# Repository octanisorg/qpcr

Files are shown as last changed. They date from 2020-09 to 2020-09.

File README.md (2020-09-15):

# Octanis qPCR

Quantitative PCR or sometimes called real-time PCR is a method to amplify a target DNA molecule and monitor its replication via fluorescence. The objective of this Octanis qPCR is to build a reliable and open qPCR machine for research purposes.

## COVID-19 and PCR

COVID-19 testing involves qPCR machines where an additional step needs to be completed prior to amplification. Using an enzyme called [Reverse Transcriptase](https://en.wikipedia.org/wiki/Reverse_transcriptase) the viral RNA is turned into DNA that the [Polymerase](https://en.wikipedia.org/wiki/Polymerase) can work with. 

## Current state

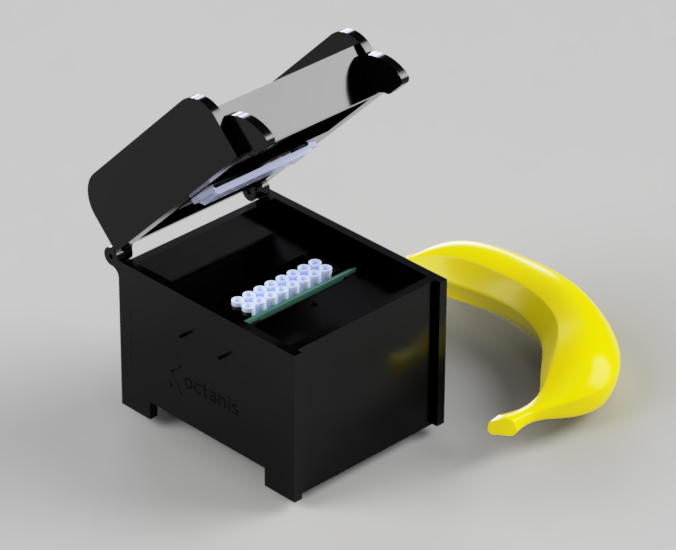
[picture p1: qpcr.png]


We are currently working on assembling the first PCBs and writing firmware. As we finalize the first prototype we will be updating this repository with our work in progress. 

If you are interested in contributing to the project [DM us](https://twitter.com/octanisorg). there are lots of cool sub-projects:
- STM32 firmware development
- SPICE simulation
- Case design
- Device GUI development

On our task list:
- Publication of an eBOM and mBOM.
- Collaboration with somebody making PCR tests/master mixes.
- Complete assembly as a STEP file. 

Completed:
- [Lid Heater PCB](https://pcb.im/share/dadb9a33574c403e)
- [16 Channel Excitation PCB](https://pcb.im/share/144b98556b9944f6)
- [8 Channel Emmision Sensing PCB](https://pcb.im/share/420ee10b3fee4fb8)
- [mainboard PCB](http://pcb.im/share/4b724f7b39da497d)

## Acknowledgements
- Chaibio, for the block and lid heater design, which we slightly modified.

## Sponsors
- [Octanis Instruments GmbH](https://www.octanis.ch) is helping with engineering and manufacturing.

## Similar projects
- [Chai Open qPCR](https://www.chaibio.com/openqpcr)
- [Ninja PCR](https://hackaday.io/project/174501-covid-19-detectors-300-real-time-pcr-50-lamp)

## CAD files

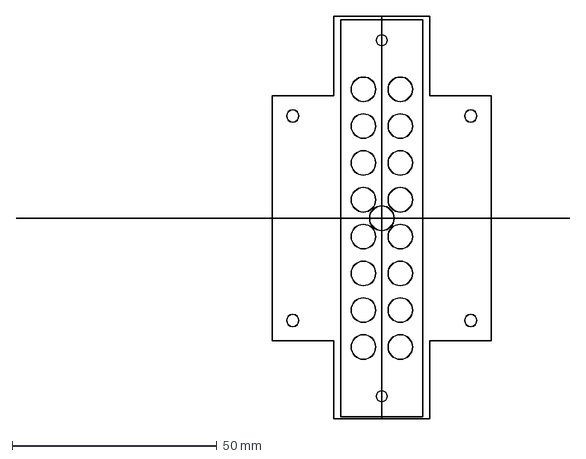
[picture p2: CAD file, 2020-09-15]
electronics/excitation-pcb/rev0/cutout.dxf
135.4 x 98.5 mm

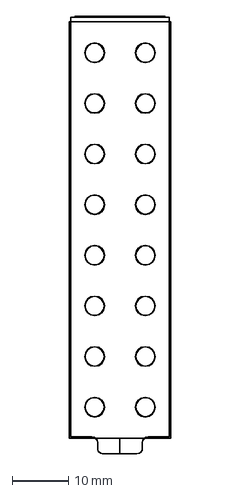
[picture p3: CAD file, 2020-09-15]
electronics/lidheater-pcb/rev0/cutout.dxf
18.0 x 77.8 mm

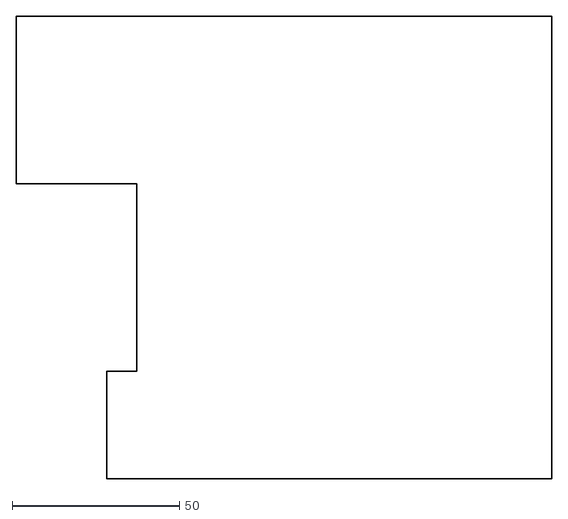
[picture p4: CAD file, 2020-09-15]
electronics/mainboard-pcb/rev0/qpcr_pcb_edge_cuts.dxf
160.0 x 138.0

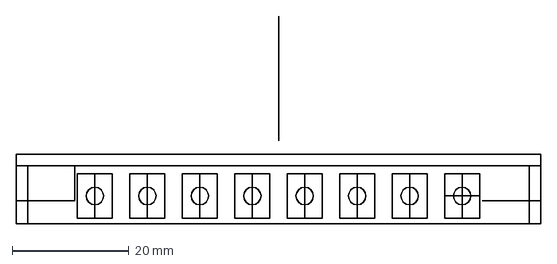
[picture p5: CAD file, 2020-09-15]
electronics/photodiode-pcb/rev0/cutout.dxf
90.0 x 35.7 mm

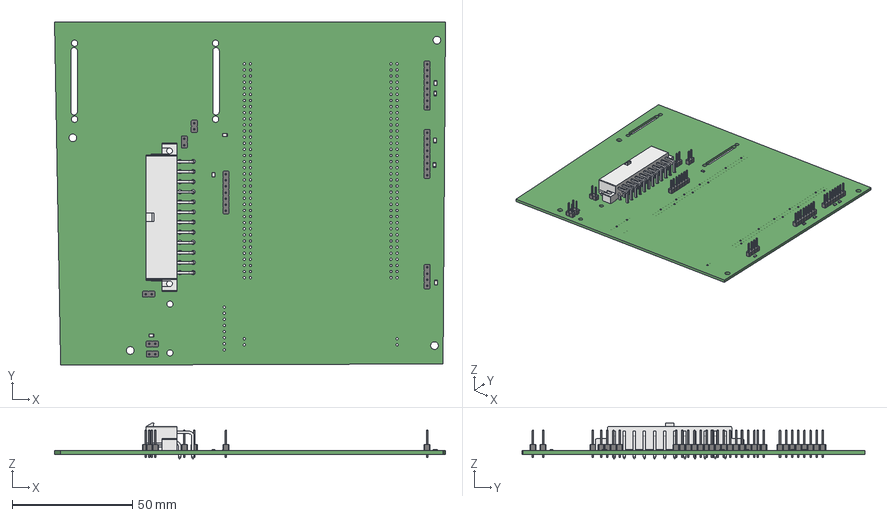
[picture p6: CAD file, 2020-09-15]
electronics/mainboard-pcb/3D_models/pcb_model.fcstd
162.6 x 142.7 x 14.9 mm

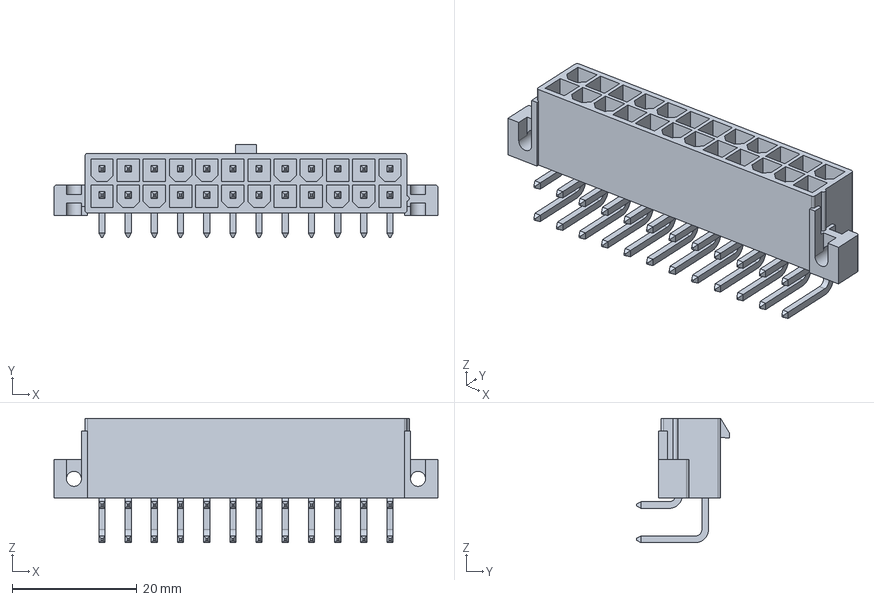
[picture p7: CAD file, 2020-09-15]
electronics/mainboard-pcb/3D_models/39291248.stp
61.6 x 14.9 x 19.9 mm

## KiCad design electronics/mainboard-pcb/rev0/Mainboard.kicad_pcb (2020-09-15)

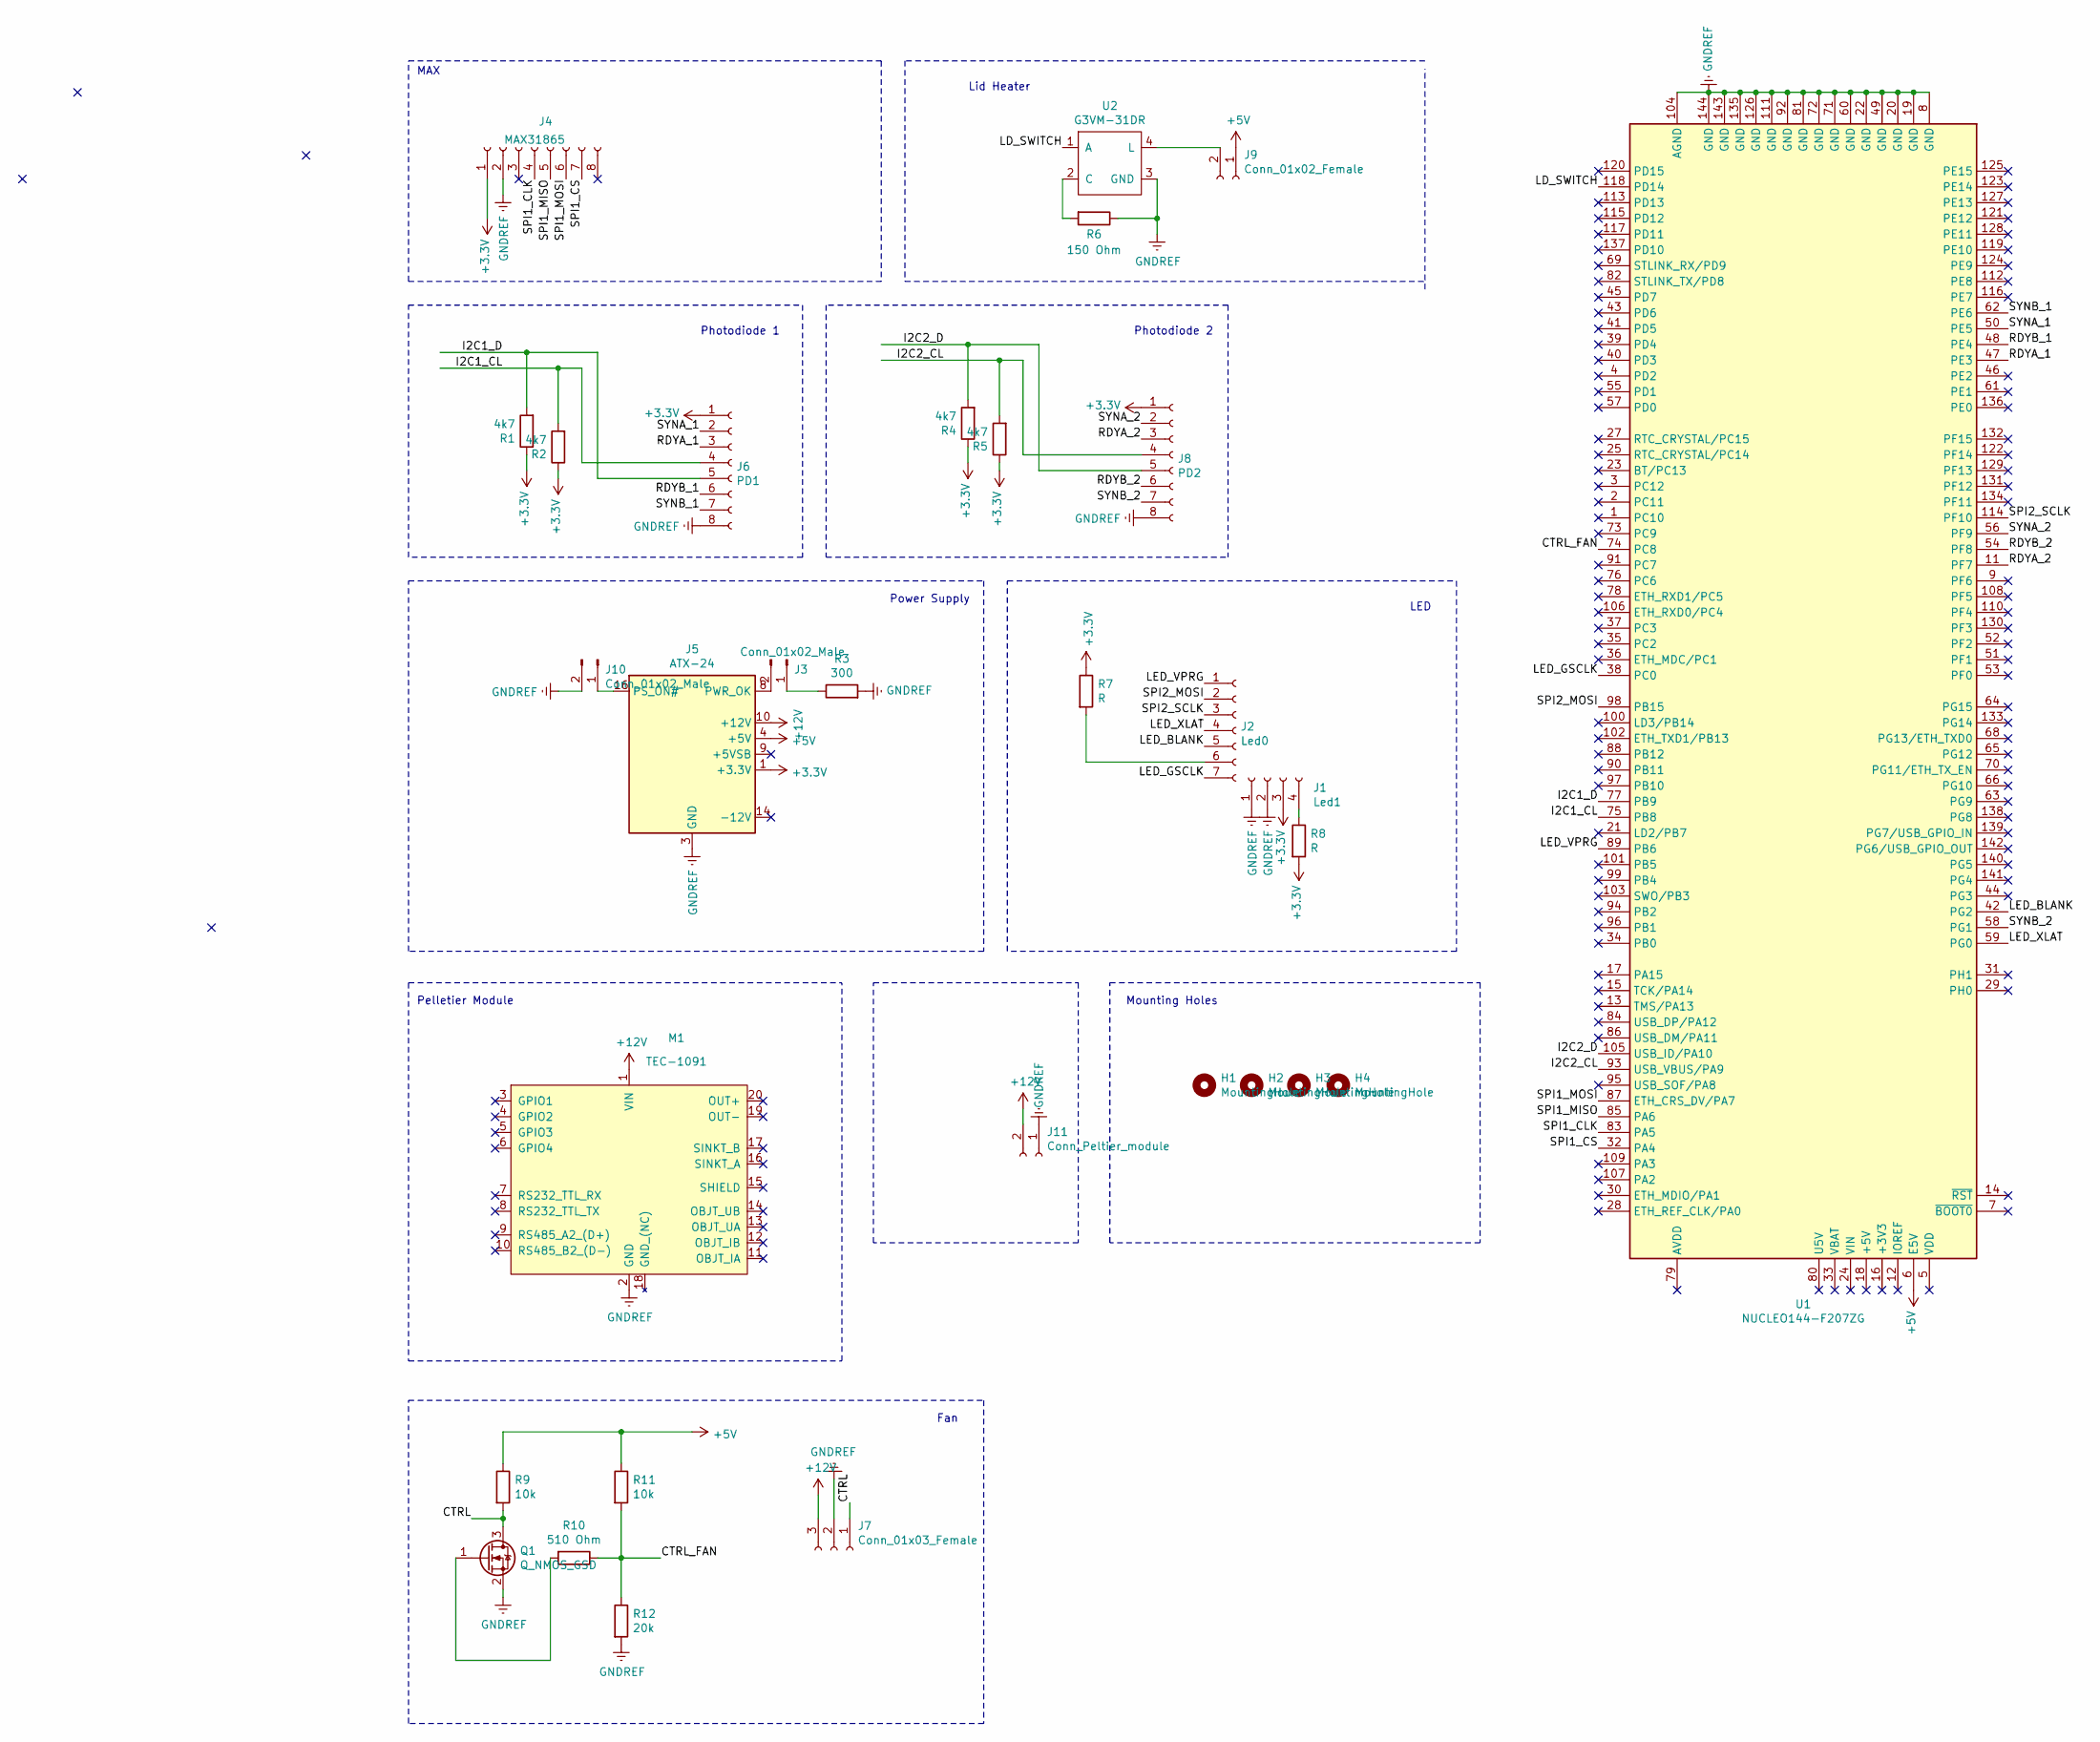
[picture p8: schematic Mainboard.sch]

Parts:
H1, H2, H3, H4: MountingHole; MountingHole_3.2mm_M3
J1: Led1; PinHeader_1x04_P2.54mm_Vertical
J2: Led0; PinHeader_1x07_P2.54mm_Vertical
J3, J10: Conn_01x02_Male; PinHeader_1x02_P2.54mm_Vertical
J4: MAX31865
J5: ATX-24; Molex_Mini-Fit_Jr_5569-24A1_2x12_P4.20mm_Horizontal; MPN 39291248
J6: PD1; PinHeader_1x08_P2.54mm_Vertical
J7: Conn_01x03_Female; PinHeader_1x03_P2.54mm_Vertical
J8: PD2; PinHeader_1x08_P2.54mm_Vertical
J9: Conn_01x02_Female; PinHeader_1x02_P2.54mm_Vertical
J11: Conn_Peltier_module; PinHeader_1x02_P2.54mm_Vertical
M1: TEC-1091; TEC-1091_alternate_pads; MPN TEC-1091
Q1: Q_NMOS_GSD; SOT-323_SC-70_Handsoldering; MPN SSM3K345R,LF
R1, R2, R4, R5: 4k7; R_0805_2012Metric_Pad1.15x1.40mm_HandSolder
R3: 300; R_0805_2012Metric_Pad1.15x1.40mm_HandSolde
R6: 150 Ohm; R_0805_2012Metric_Pad1.15x1.40mm_HandSolde
R7, R8: R; R_0805_2012Metric_Pad1.15x1.40mm_HandSolder
R9, R11: 10k; R_0805_2012Metric_Pad1.15x1.40mm_HandSolder
R10: 510 Ohm; R_0805_2012Metric_Pad1.15x1.40mm_HandSolder
R12: 20k; R_0805_2012Metric_Pad1.15x1.40mm_HandSolder
U1: NUCLEO144-F207ZG; ST_Morpho_Connector_144_STLink; MPN2 NUCLEO-F303ZE
U2: G3VM-31DR; MPN G3VM-31DR

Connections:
+3V3: J1.3, J4.1, J5.1 (+3.3V), J5.2 (+3.3V), J5.12 (+3.3V), J5.13 (+3.3V), J6.1, J8.1, R1.1, R2.1, R4.1, R5.1, R7.1, R8.2
+5V: J5.4 (+5V), J5.6 (+5V), J5.21 (+5V), J5.22 (+5V), J5.23 (+5V), J9.1, R9.1, R11.1, U1.6 (E5V)
+12V: J5.10 (+12V), J5.11 (+12V), J7.3, J11.2, M1.1 (VIN)
/CTRL: J7.1, Q1.3 (D), R9.2
/CTRL_FAN: R10.1, R11.2, R12.1, U1.74 (PC8)
/I2C1_CL: J6.4, R2.2, U1.75 (PB8)
/I2C1_D: J6.5, R1.2, U1.77 (PB9)
/I2C2_CL: J8.4, R5.2, U1.93 (USB_VBUS/PA9)
/I2C2_D: J8.5, R4.2, U1.105 (USB_ID/PA10)
/LD_SWITCH: U1.118 (PD14), U2.1 (A)
/LED_BLANK: J2.5, U1.42 (PG2)
/LED_GSCLK: J2.7, U1.38 (PC0)
/LED_VPRG: J2.1, U1.89 (PB6)
/LED_XLAT: J2.4, U1.59 (PG0)
/RDYA_1: J6.3, U1.47 (PE3)
/RDYA_2: J8.3, U1.11 (PF7)
/RDYB_1: J6.6, U1.48 (PE4)
/RDYB_2: J8.6, U1.54 (PF8)
/SPI1_CLK: J4.4, U1.83 (PA5)
/SPI1_CS: J4.7, U1.32 (PA4)
/SPI1_MISO: J4.5, U1.85 (PA6)
/SPI1_MOSI: J4.6, U1.87 (ETH_CRS_DV/PA7)
/SPI2_MOSI: J2.2, U1.98 (PB15)
/SPI2_SCLK: J2.3, U1.114 (PF10)
/SYNA_1: J6.2, U1.50 (PE5)
/SYNA_2: J8.2, U1.56 (PF9)
/SYNB_1: J6.7, U1.62 (PE6)
/SYNB_2: J8.7, U1.58 (PG1)
GNDREF: J1.1, J1.2, J4.2, J5.3 (GND), J5.5 (GND), J5.7 (GND), J5.15 (GND), J5.17 (GND), J5.18 (GND), J5.19 (GND), J5.24 (GND), J6.8, J7.2, J8.8, J10.2, J11.1, M1.2 (GND), Q1.2 (S), R3.2, R6.1, R12.2, U1.8 (GND), U1.19 (GND), U1.20 (GND), U1.22 (GND), U1.49 (GND), U1.60 (GND), U1.71 (GND), U1.72 (GND), U1.81 (GND), U1.92 (GND), U1.104 (AGND), U1.111 (GND), U1.126 (GND), U1.135 (GND), U1.143 (GND), U1.144 (GND), U2.3 (GND)
unnamed: J1.4, R8.1
unnamed: J2.6, R7.2
unnamed: J3.1, R3.1
unnamed: J3.2, J5.8 (PWR_OK)
unnamed: J9.2, U2.4 (L)
unnamed: J5.16 (PS_ON#), J10.1
unnamed: Q1.1 (G), R10.2
unnamed: R6.2, U2.2 (C)

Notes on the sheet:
Lid Heater
Power Supply
MAX
Photodiode 1
Photodiode 2
LED
Pelletier Module
Fan
Mounting Holes

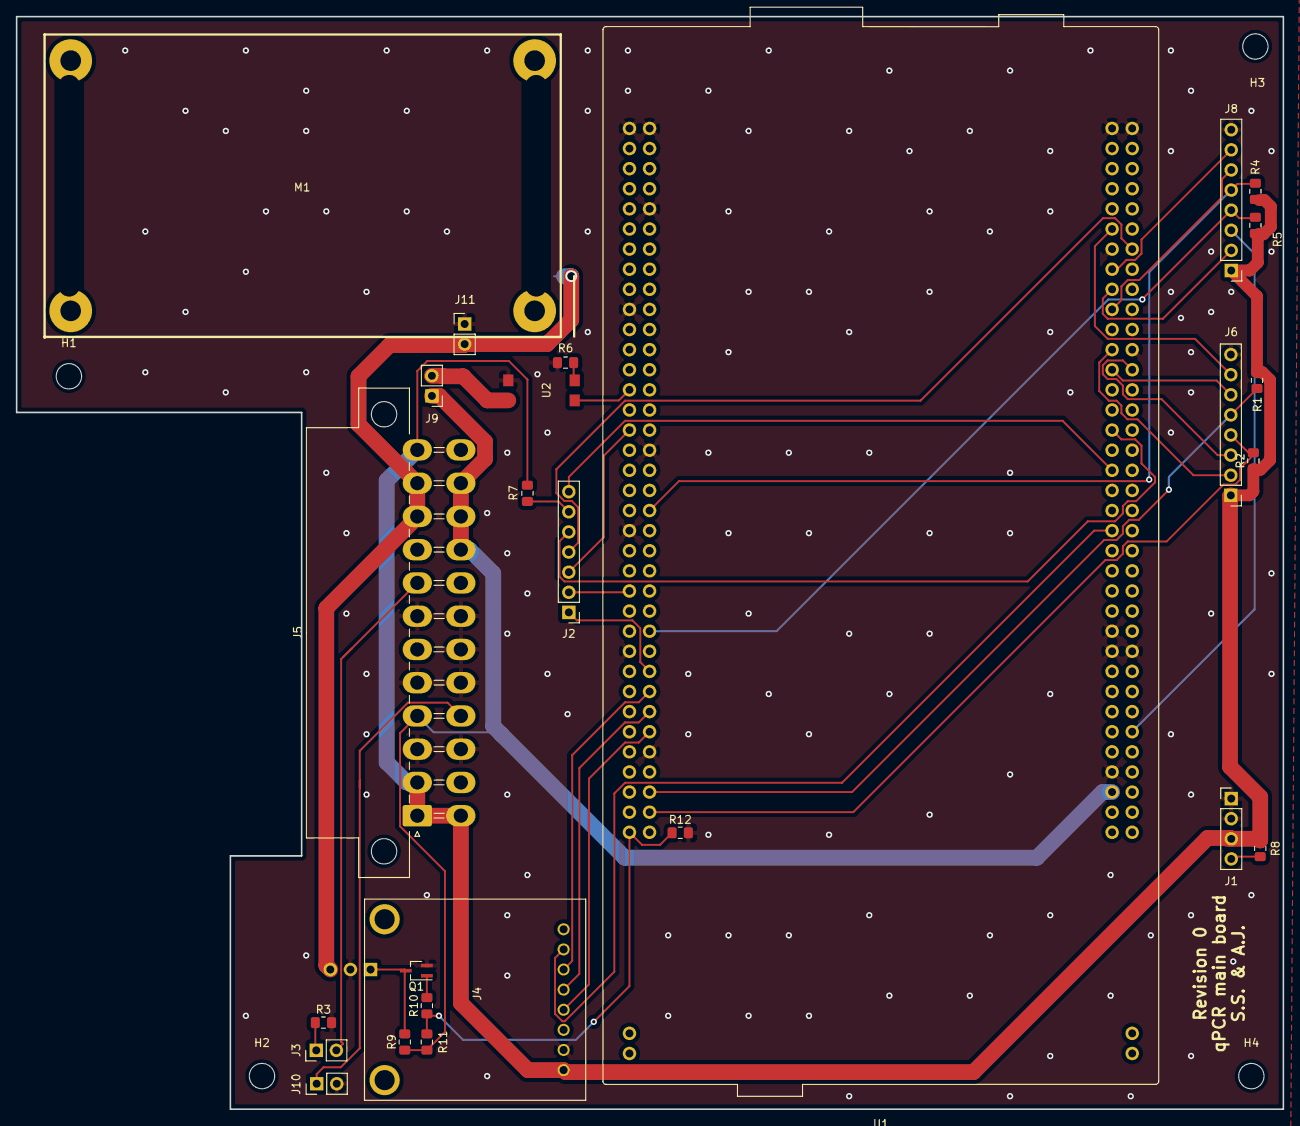
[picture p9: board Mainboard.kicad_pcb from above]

Board: 2 copper layers, 160.0 x 138.0 mm, 31 parts (1 on the bottom side), 37 nets.

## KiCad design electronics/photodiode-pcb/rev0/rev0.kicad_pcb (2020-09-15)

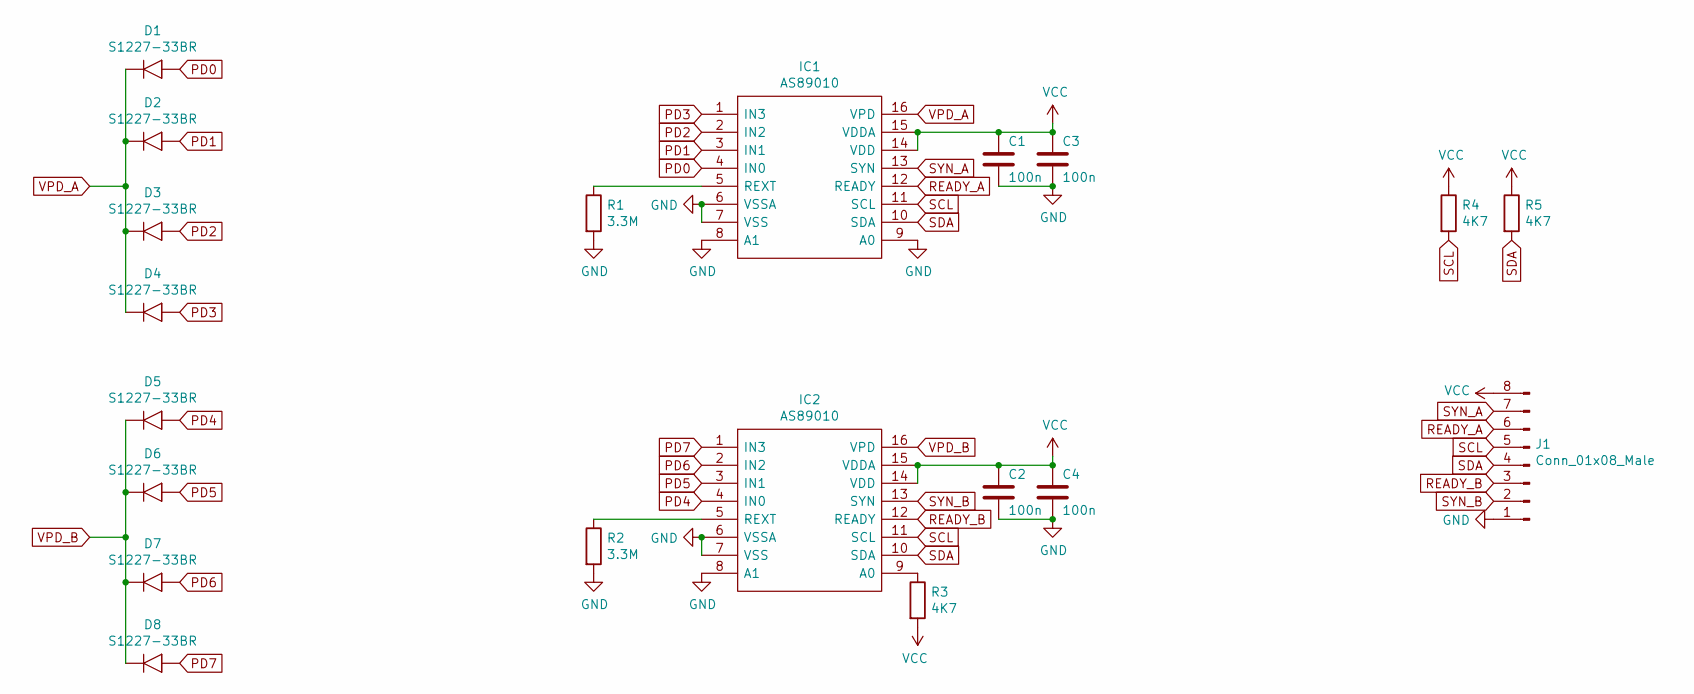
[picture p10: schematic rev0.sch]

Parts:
C1, C2, C3, C4: 100n; C_0402_1005Metric
D1, D2, D3, D4, D5, D6, D7, D8: S1227-33BR; MPN S1227-33BR
IC1, IC2: AS89010; SOP64P600X175-16N; Manufacturer_Part_Number AS89010; Mouser Part Number 985-AS89010
J1: Conn_01x08_Male; PinHeader_1x08_P1.00mm_Vertical
R1, R2: 3.3M; R_1206_3216Metric
R3, R4, R5: 4K7; R_0402_1005Metric

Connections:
GND: C1.2, C2.2, C3.2, C4.2, IC1.6 (VSSA), IC1.7 (VSS), IC1.8 (A1), IC1.9 (A0), IC2.6 (VSSA), IC2.7 (VSS), IC2.8 (A1), J1.1, R1.2, R2.2
unnamed: IC1.5 (REXT), R1.1
unnamed: IC2.5 (REXT), R2.1
unnamed: IC2.9 (A0), R3.1
PD0: D1.1, IC1.4 (IN0)
PD1: D2.1, IC1.3 (IN1)
PD2: D3.1, IC1.2 (IN2)
PD3: D4.1, IC1.1 (IN3)
PD4: D5.1, IC2.4 (IN0)
PD5: D6.1, IC2.3 (IN1)
PD6: D7.1, IC2.2 (IN2)
PD7: D8.1, IC2.1 (IN3)
READY_A: IC1.12 (READY), J1.6
READY_B: IC2.12 (READY), J1.3
SCL: IC1.11 (SCL), IC2.11 (SCL), J1.5, R4.2
SDA: IC1.10 (SDA), IC2.10 (SDA), J1.4, R5.2
SYN_A: IC1.13 (SYN), J1.7
SYN_B: IC2.13 (SYN), J1.2
VCC: C1.1, C2.1, C3.1, C4.1, IC1.14 (VDD), IC1.15 (VDDA), IC2.14 (VDD), IC2.15 (VDDA), J1.8, R3.2, R4.1, R5.1
VPD_A: D1.2, D2.2, D3.2, D4.2, IC1.16 (VPD)
VPD_B: D5.2, D6.2, D7.2, D8.2, IC2.16 (VPD)

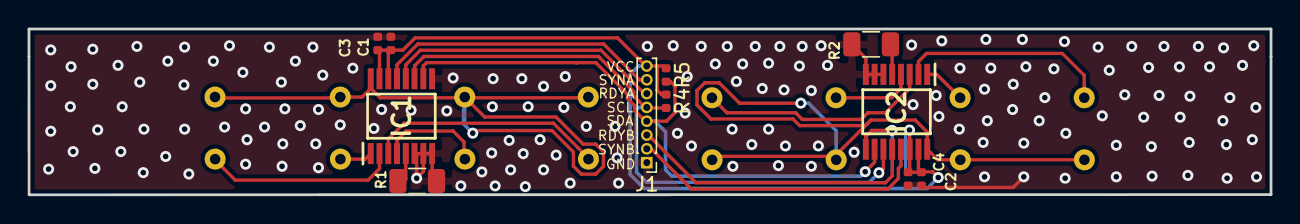
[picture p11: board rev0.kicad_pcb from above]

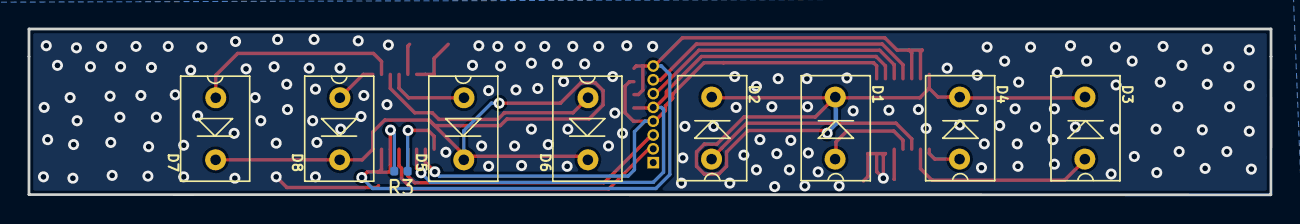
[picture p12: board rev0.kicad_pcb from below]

Board: 2 copper layers, 90.0 x 12.0 mm, 20 parts (9 on the bottom side), 21 nets.

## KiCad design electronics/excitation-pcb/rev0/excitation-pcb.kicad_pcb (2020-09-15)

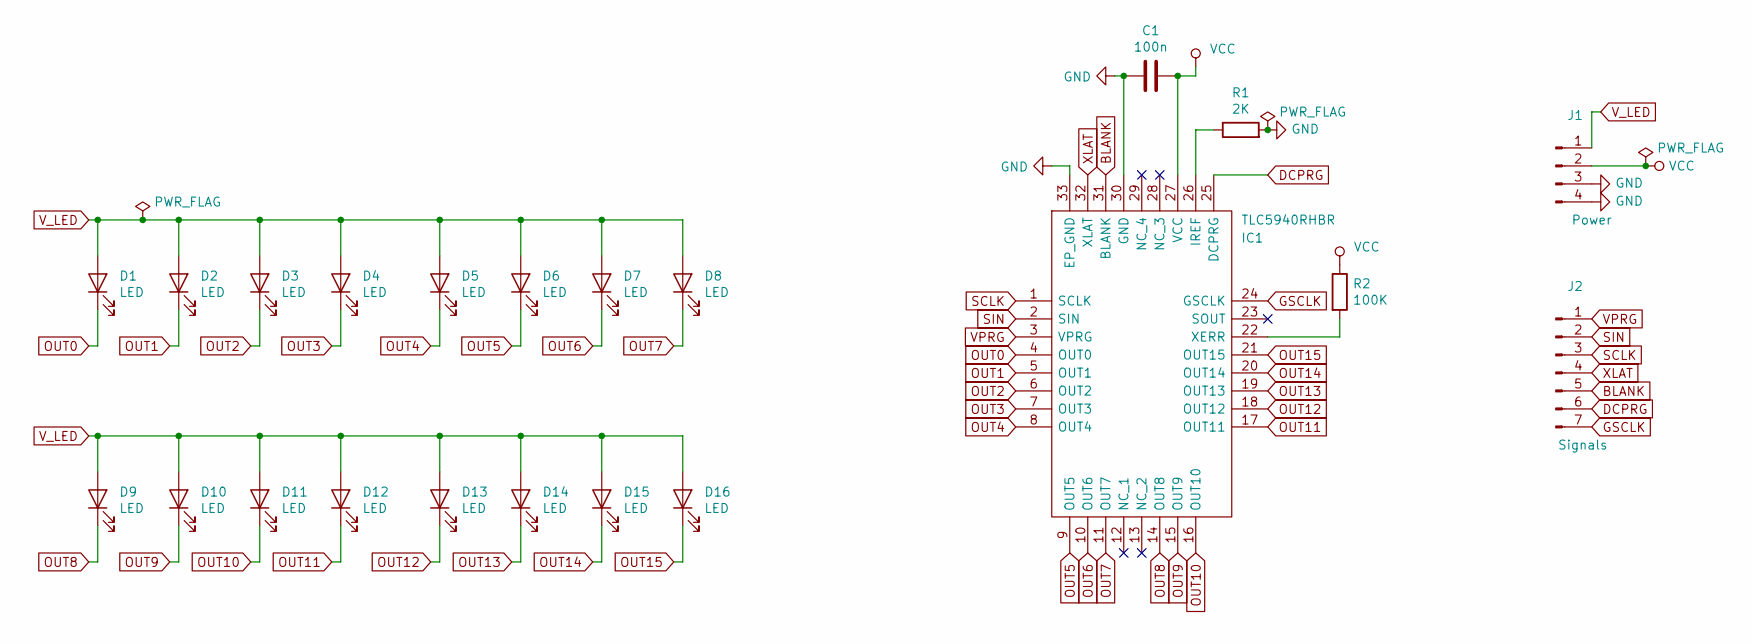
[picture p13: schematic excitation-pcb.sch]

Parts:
C1: 100n; C_0603_1608Metric
D1: LED; LED_D5.0mm; MPN C503B-BAS-CY0C0461
D2, D3, D4, D5, D6, D7, D8, D9, D10, D11, D12, D13, D14, D15, D16: LED; LED_D5.0mm
IC1: TLC5940RHBR; QFN50P500X500X100-33N-D; Manufacturer_Part_Number TLC5940RHBR; Mouser Part Number 595-TLC5940RHBR
J1: Power; PinHeader_1x04_P2.54mm_Vertical
J2: Signals; PinHeader_1x07_P2.54mm_Vertical
R1: 2K; R_0603_1608Metric
R2: 100K; R_0603_1608Metric

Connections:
BLANK: IC1.31 (BLANK), J2.5
DCPRG: IC1.25 (DCPRG), J2.6
GND: C1.2, IC1.30 (GND), IC1.33 (EP_GND), J1.3, J1.4, R1.2
GSCLK: IC1.24 (GSCLK), J2.7
unnamed: IC1.22 (XERR), R2.2
unnamed: IC1.26 (IREF), R1.1
OUT0: D1.1 (K), IC1.4 (OUT0)
OUT1: D2.1 (K), IC1.5 (OUT1)
OUT2: D3.1 (K), IC1.6 (OUT2)
OUT3: D4.1 (K), IC1.7 (OUT3)
OUT4: D5.1 (K), IC1.8 (OUT4)
OUT5: D6.1 (K), IC1.9 (OUT5)
OUT6: D7.1 (K), IC1.10 (OUT6)
OUT7: D8.1 (K), IC1.11 (OUT7)
OUT8: D9.1 (K), IC1.14 (OUT8)
OUT9: D10.1 (K), IC1.15 (OUT9)
OUT10: D11.1 (K), IC1.16 (OUT10)
OUT11: D12.1 (K), IC1.17 (OUT11)
OUT12: D13.1 (K), IC1.18 (OUT12)
OUT13: D14.1 (K), IC1.19 (OUT13)
OUT14: D15.1 (K), IC1.20 (OUT14)
OUT15: D16.1 (K), IC1.21 (OUT15)
SCLK: IC1.1 (SCLK), J2.3
SIN: IC1.2 (SIN), J2.2
VCC: C1.1, IC1.27 (VCC), J1.2, R2.1
VPRG: IC1.3 (VPRG), J2.1
V_LED: D1.2 (A), D2.2 (A), D3.2 (A), D4.2 (A), D5.2 (A), D6.2 (A), D7.2 (A), D8.2 (A), D9.2 (A), D10.2 (A), D11.2 (A), D12.2 (A), D13.2 (A), D14.2 (A), D15.2 (A), D16.2 (A), J1.1
XLAT: IC1.32 (XLAT), J2.4

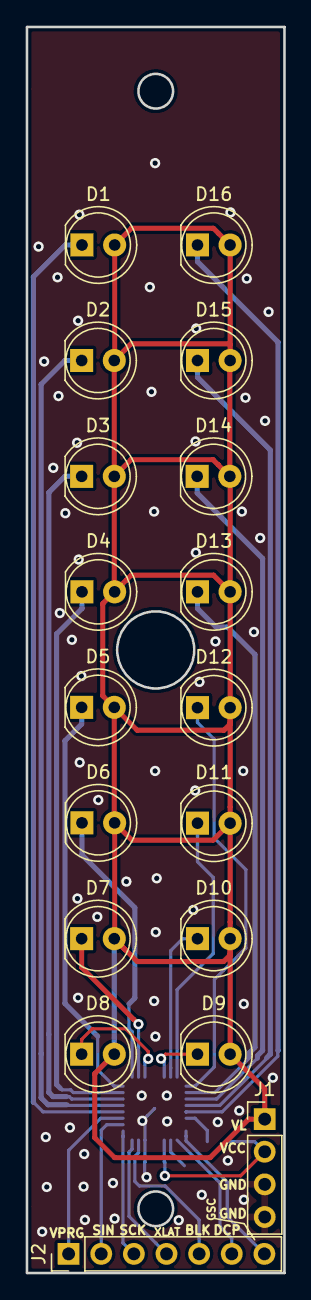
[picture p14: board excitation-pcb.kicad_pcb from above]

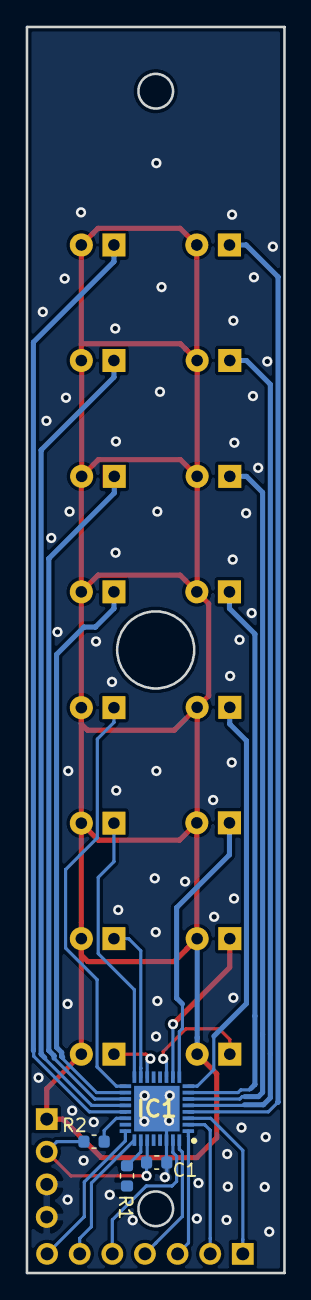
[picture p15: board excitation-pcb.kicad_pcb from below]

Board: 2 copper layers, 20.0 x 97.0 mm, 22 parts (4 on the bottom side), 28 nets.

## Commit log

2020-09-15 adding excitation, lidheater and photodiode pcbs from gitlab
    [cutout.dxf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]
2020-09-15 updating README. fixing edge_cuts in emmision pcb.
    [rev0.kicad_pcb]
2020-09-15 adding mainboard PCB, updating README
    [39291248.stp, Mainboard.kicad_pcb, Mainboard.sch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]

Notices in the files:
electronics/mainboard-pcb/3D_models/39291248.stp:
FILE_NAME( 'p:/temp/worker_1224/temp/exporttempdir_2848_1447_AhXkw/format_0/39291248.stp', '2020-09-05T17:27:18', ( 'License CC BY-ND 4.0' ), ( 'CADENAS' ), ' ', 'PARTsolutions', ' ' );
